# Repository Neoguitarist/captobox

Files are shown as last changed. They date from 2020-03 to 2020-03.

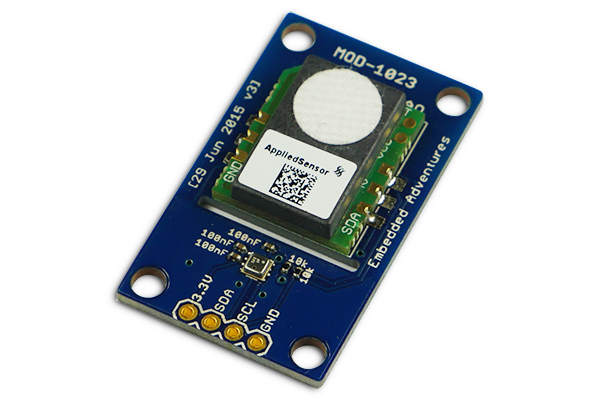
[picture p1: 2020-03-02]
resources/CAO boitier/img/cov.jpg

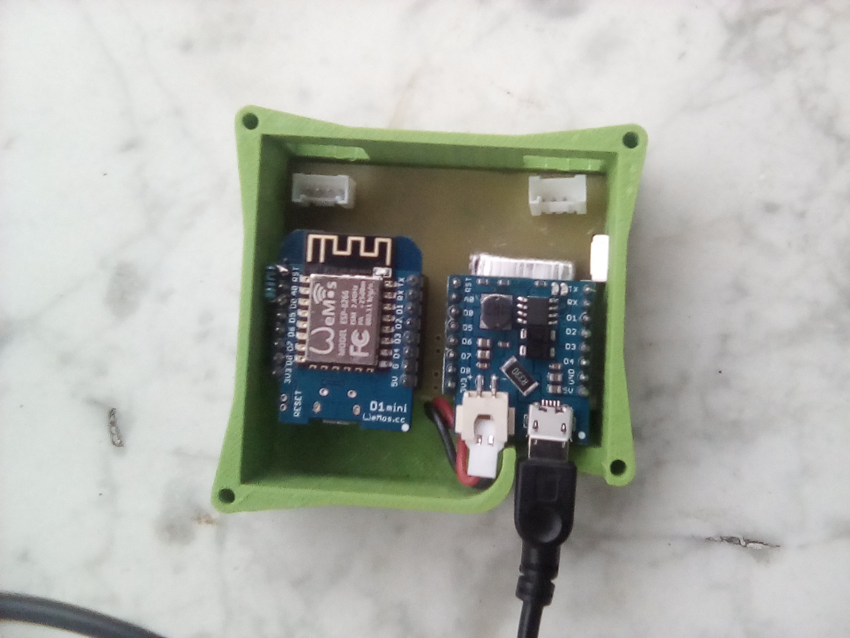
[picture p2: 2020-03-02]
resources/CAO boitier/captoboite.jpg

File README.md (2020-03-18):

**Introduction**

Ce GitHub est basé sur celui de Julien Rat : https://github.com/julienrat/captobox .

Le code a été fortement restructuré, et de nouveaux capteurs sont pris en charge.

**Capteurs pris en charge actuellement**

- M0D1023 (incluant BME280 et iAQ) :
	- MOD1023 : http://www.embeddedadventures.com/bme280_AMS-IAQ_multi_sensor_mod-1023.html
	- BME280 : https://www.bluedot.space/sensor-boards/bme280/
- BME680 : https://joy-it.net/en/products/SEN-BME680
- CCS811 : https://joy-it.net/en/products/SEN-CCS811V1

**Prise en main**

Dans le dossier "resources/prise en main", vous trouverez deux documents essentiels :
- "Description matos.pdf" : liste avec photos de l'ensemble du matériel constituant une Captobox.
- "Branchements captobox.pdf" : guide pour le branchement des différents capteurs sur le module cerveau.

**Note importante**

À l'heure actuelle, il est nécessaire de redémarrer la carte lorsqu'on change de capteur, pour que celui-ci soit détecté.

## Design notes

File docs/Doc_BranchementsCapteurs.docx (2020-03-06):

Résultat de recherche d'images pour "wemos d1 mini pull up"

Mod 1023=

- BME280 : temperature, humidity and absolute air pressure sensor

- IAQ : VOCs and C02 measurements

I2C requires the use of pull-up resistors. The board comes with the pull-up resistors enabled. If you are connecting to an existing I2C buss that already has pull-up resistors, or you are using internal pull-ups in your microcontroller, you can disable the pull-up resistors by unsoldering the 10k resistors from theMOD-1023board and making sure the pads are not connected with any residual solder. Having extra pull-ups won’t hurt anything, other than a very marginal increase in power consumption.

The AMS-IAQ takes 5 minutes to settle until first reading is available, duringwhich time it will show an ERROR reading from thestatus register

TEST:

MARCHE PAS :

MOD1023 Humidity 100pourcent sur capteur 1 et capt2 avec temperature en 2eme ?

MARCHE :

Temperature et Pression marche capt1/2 2/1

Pression et pression marche

Temp et temp marche

Temperature et CO2 marche cap1/2 et 2/1

VOC et CO2 capt1/2 2/1

….ect

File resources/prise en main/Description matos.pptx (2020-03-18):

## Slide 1

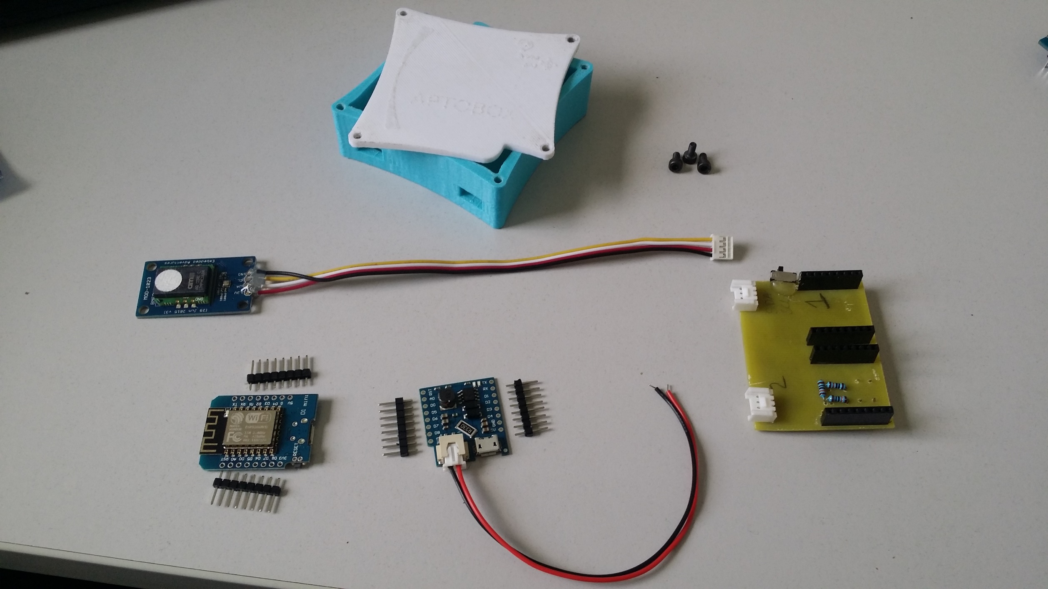
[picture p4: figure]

Boitier et couvercle
Imprimés en 3D

4 vis hexa M3 L5

capteur

Carte électronique

Nappe 4 fils
connecteur femelle

Module
Wi-Fi

broches

Module
Batterie

broches

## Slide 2

Carte électronique

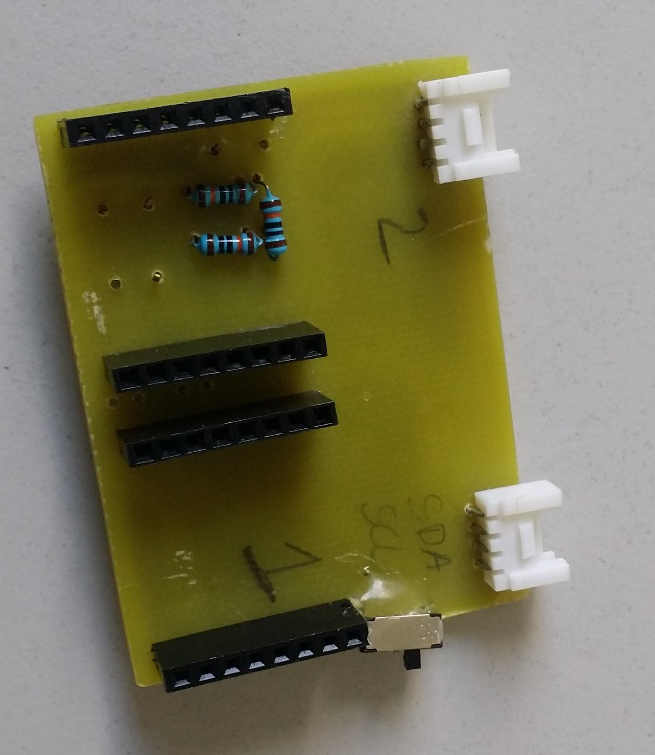
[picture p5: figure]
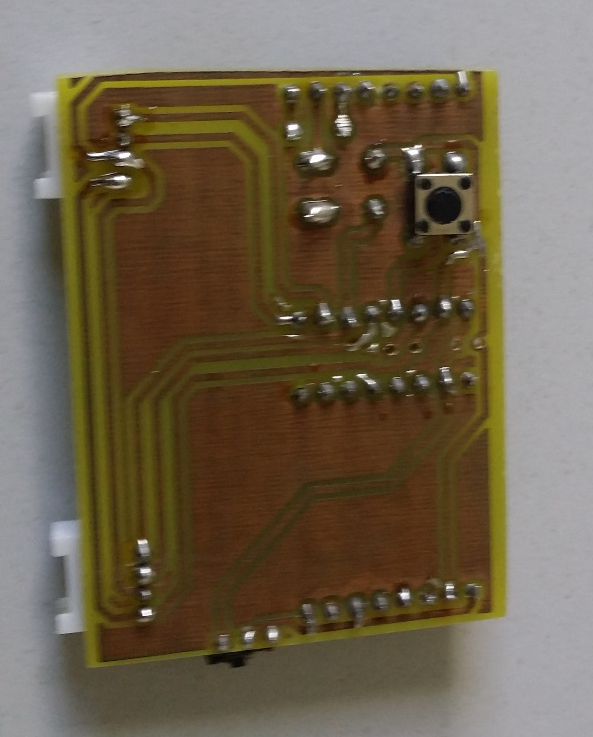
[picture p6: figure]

Bouton poussoir

Connecteurs mâle

Socket H13

Selecteur on/off

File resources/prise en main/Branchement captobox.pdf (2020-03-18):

Les petits débrouillards : Branchement Captobox

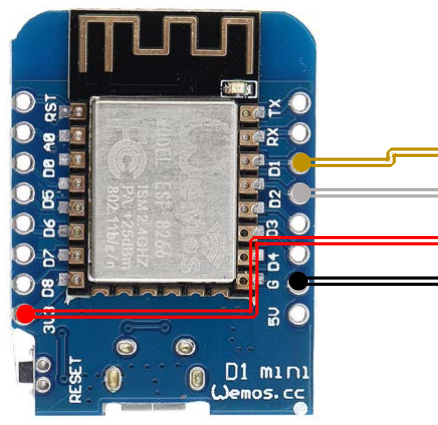
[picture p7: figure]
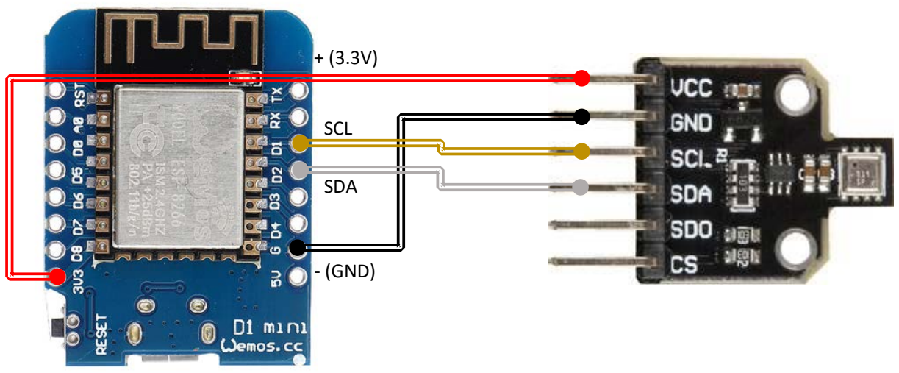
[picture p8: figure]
SDA; SCL; - (GND)

Création : 12/03/2020 par Pauline LAFOUX

Comment brancher la captobox ?
1) Le module Wemos D1 mini
C’est le « cerveau », celui qui exécute le programme. Il lis les données capteurs et les renvoie sur le wifi captobox.
Pour communiquer avec 1 ou plusieurs capteurs, il faut 4 fils :
- 2 pour l’alimentation du capteur :(+ 3.3V et – GND )
- 2 pour la communication avec le capteur (SCL et SDA)

Nous allons voir que l’on peut brancher 1 ou plusieurs capteurs en même temps
2) Les capteurs
Le BME680
Mesure : température (°C), pression (Pa), Humidité (%) et Gas (Ohm)

SDA

SCL

+ (3.3V)
- (GND)

Le CCS811
Mesure : CO2 (ppm), TVOC (ppb), température (°C)

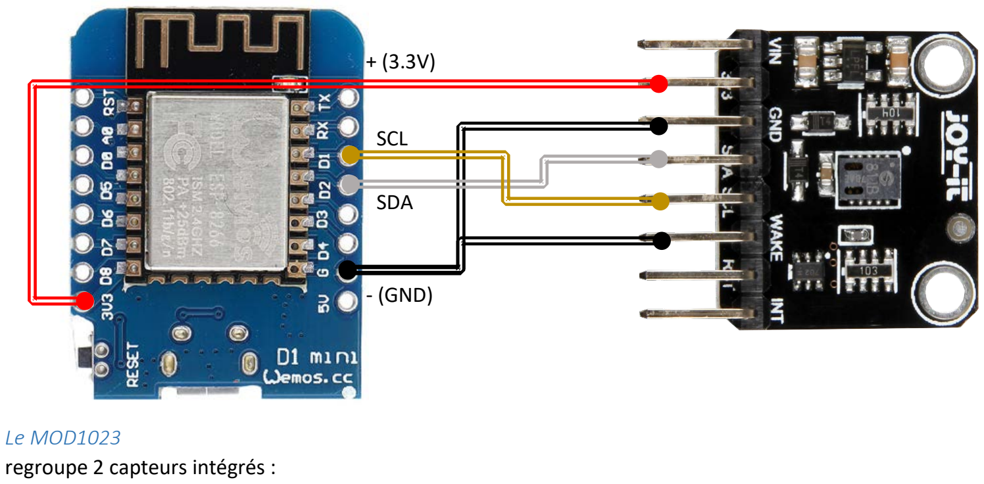
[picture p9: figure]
Le MOD1023 regroupe 2 capteurs intégrés :; SDA; SCL; - (GND)

Le BME2080 qui mesure : température (°C), humidité (%), pression (Pa)
L’IAQ qui mesure : CO2 et VOC
/!\ l’iaq a besoin de 5min pour s’initaliser avant d’afficher des valeurs valides

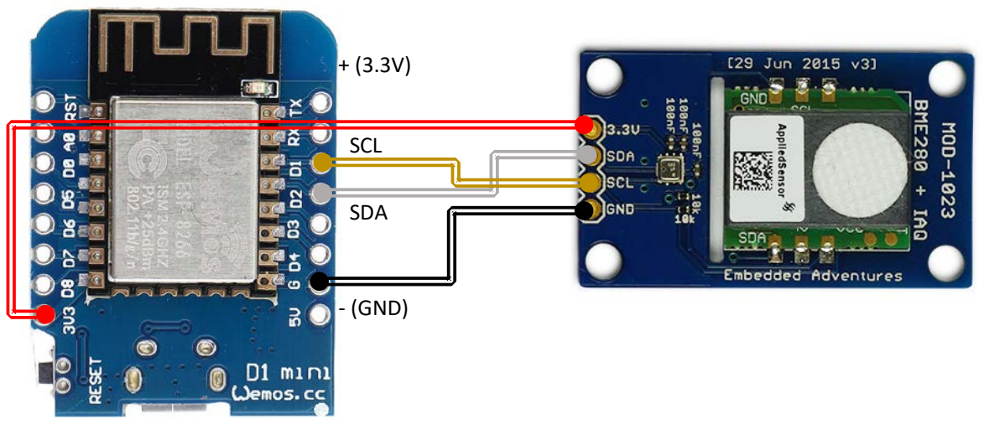
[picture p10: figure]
SDA; SCL; - (GND)

3) Branchement plusieurs capteurs
Il est possible de brancher plusieurs capteurs et de faire la lecture des données de chacun en même temps. Il suffit de faire les mêmes branchements que précédemment (en parallèle) avec tous les capteurs avec lesquels on souhaite communiquer.

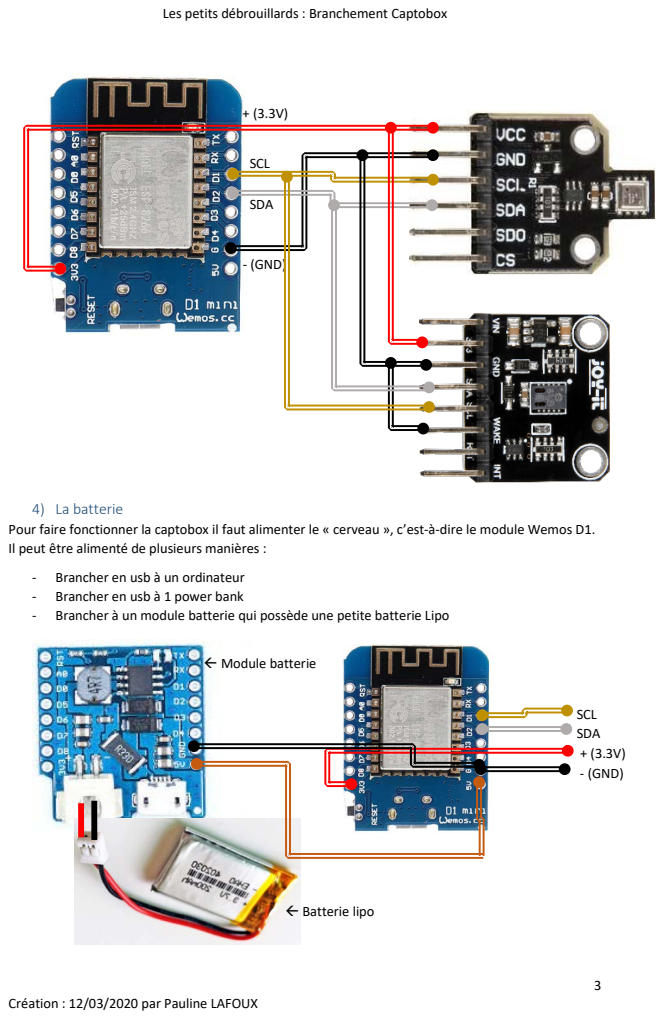
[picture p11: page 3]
SDA; SCL; - (GND); + (3.3V) - (GND); Module batterie; Batterie lipo

4) La batterie
Pour faire fonctionner la captobox il faut alimenter le « cerveau », c’est-à-dire le module Wemos D1.
Il peut être alimenté de plusieurs manières :
- Brancher en usb à un ordinateur
- Brancher en usb à 1 power bank
- Brancher à un module batterie qui possède une petite batterie Lipo

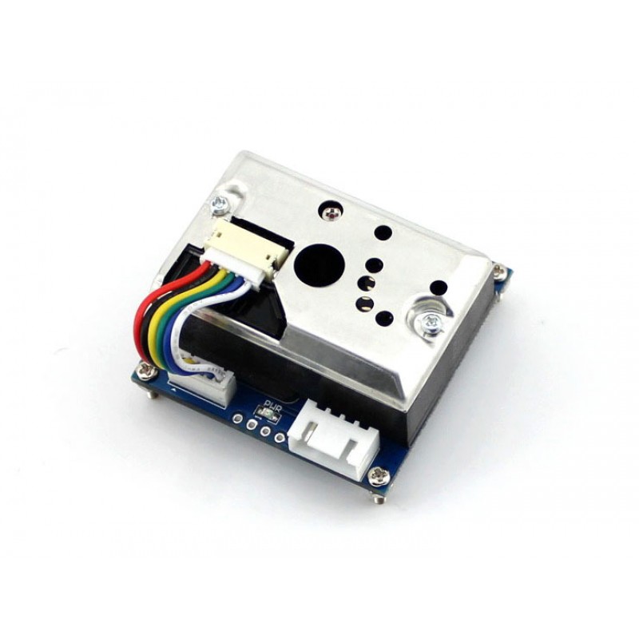
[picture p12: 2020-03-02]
resources/CAO boitier/img/dust.jpg

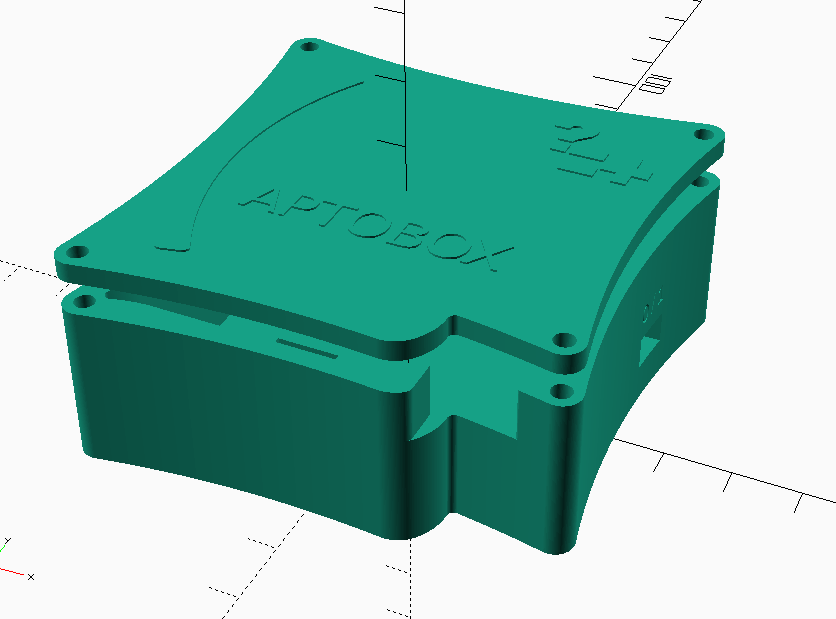
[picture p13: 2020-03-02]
resources/CAO boitier/V2/Captobox-V2.png

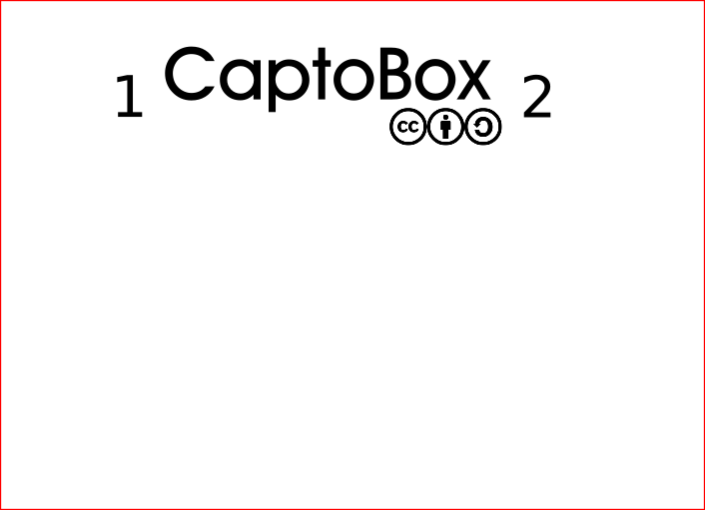
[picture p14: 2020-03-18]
resources/CAO carte électronique/fichiers sources/silk/rect133.png

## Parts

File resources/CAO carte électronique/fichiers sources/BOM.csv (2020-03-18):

Designator | Manufacturer Part Number | Quantity
SW1 | 311030008 | 1
J1,J2 | 320110034 | 2

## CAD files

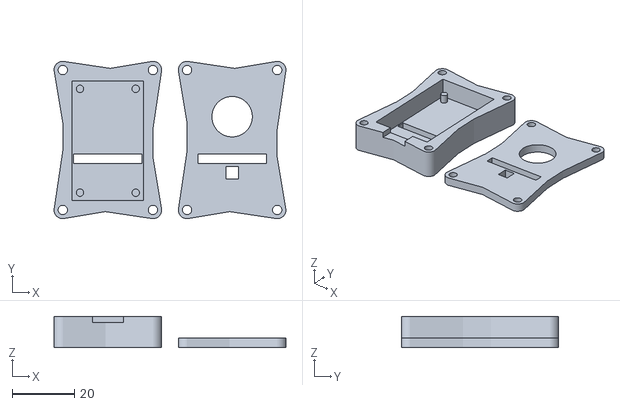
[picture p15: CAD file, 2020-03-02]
resources/CAO boitier/mod-1023.stl
74.7 x 50.7 x 10.0

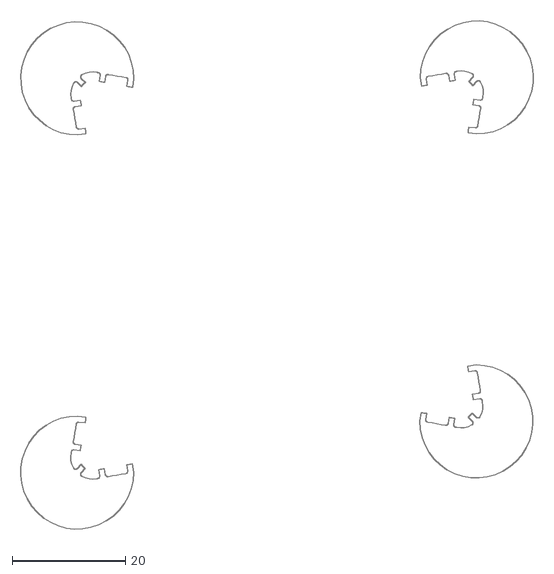
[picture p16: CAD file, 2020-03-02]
resources/CAO boitier/V2/captobox.dxf
92.3 x 91.5

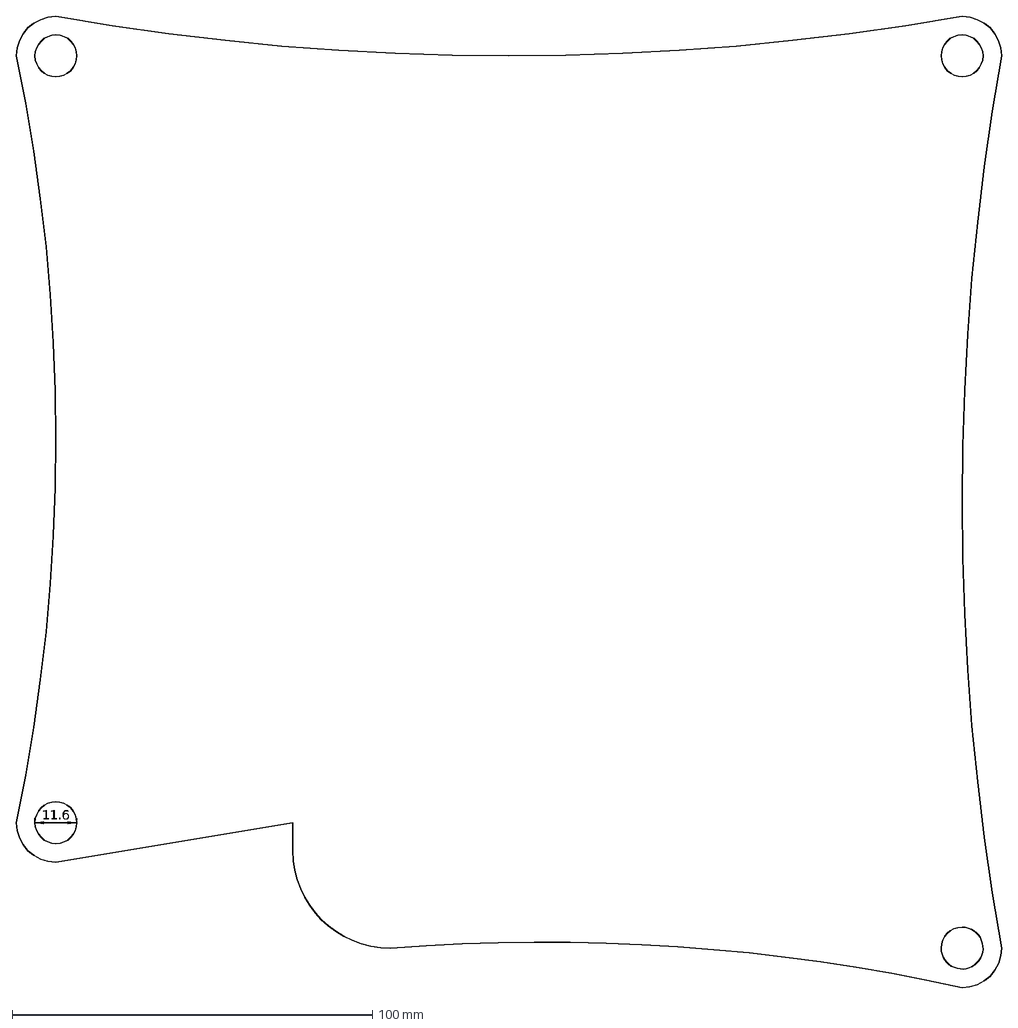
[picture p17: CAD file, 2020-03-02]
resources/CAO boitier/#capto.dxf
11.6

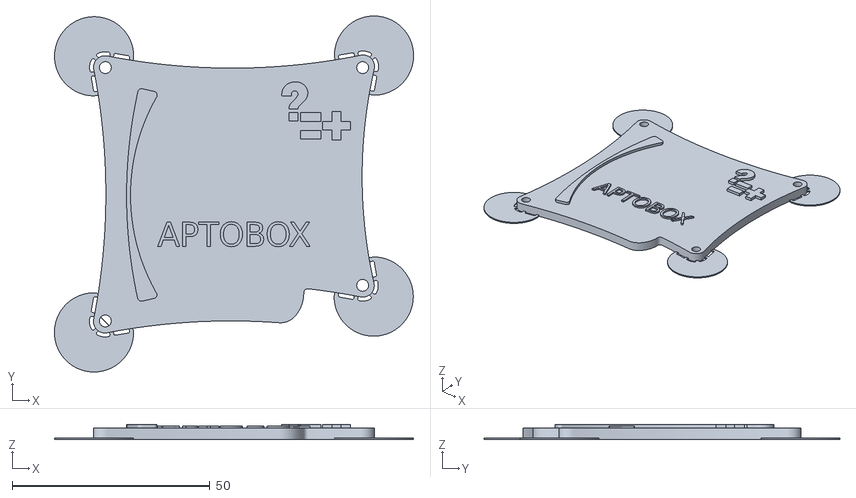
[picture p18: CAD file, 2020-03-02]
resources/CAO boitier/V2/capot-logo-support.stl
90.7 x 89.9 x 3.90

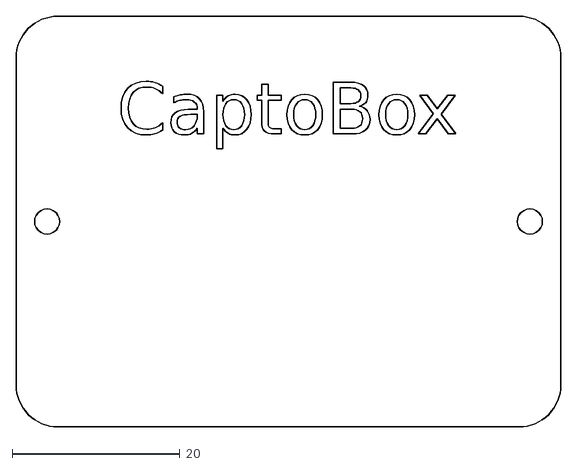
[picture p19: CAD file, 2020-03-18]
resources/CAO carte électronique/fichiers sources/silk.dxf
65.0 x 49.0

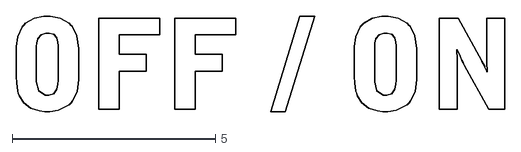
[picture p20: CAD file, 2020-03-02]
resources/CAO boitier/onoff.dxf
12.0 x 2.35

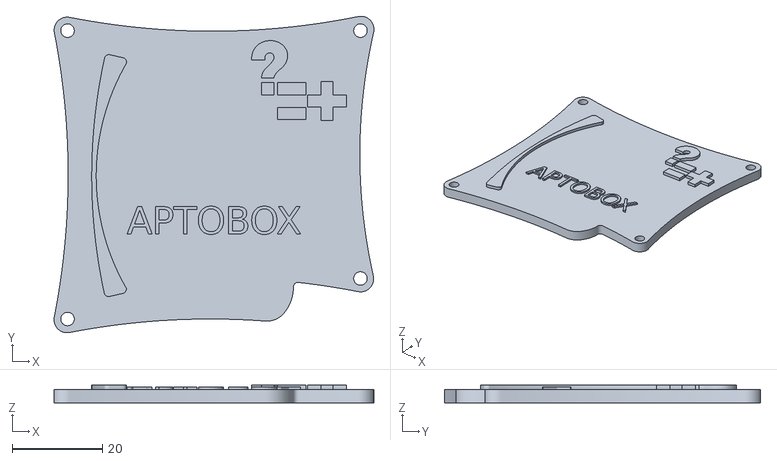
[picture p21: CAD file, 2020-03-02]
resources/CAO boitier/V2/capot-logoplusgrand-sans-support-.stl
71.0 x 70.2 x 3.90

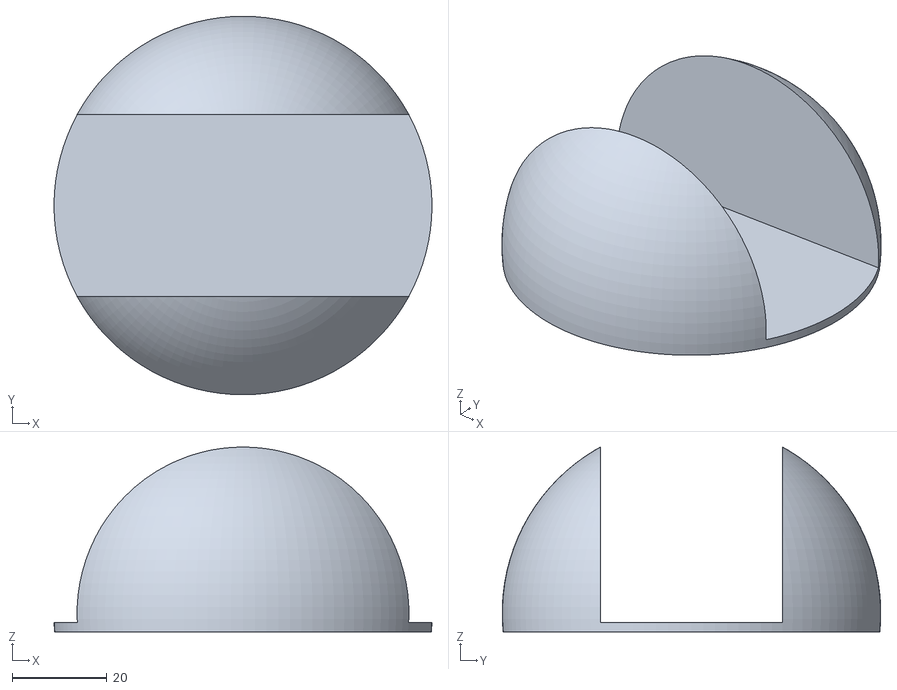
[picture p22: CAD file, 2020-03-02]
resources/CAO boitier/pied_box.stl
79.9 x 80.0 x 39.0

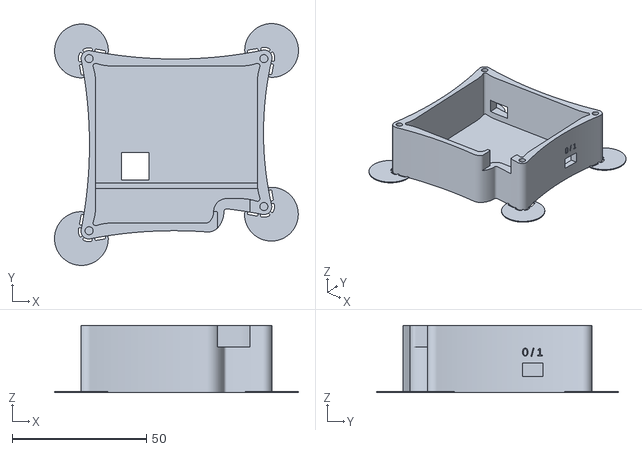
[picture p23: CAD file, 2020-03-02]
resources/CAO boitier/V2/boitier-support.stl
90.7 x 89.9 x 25.0

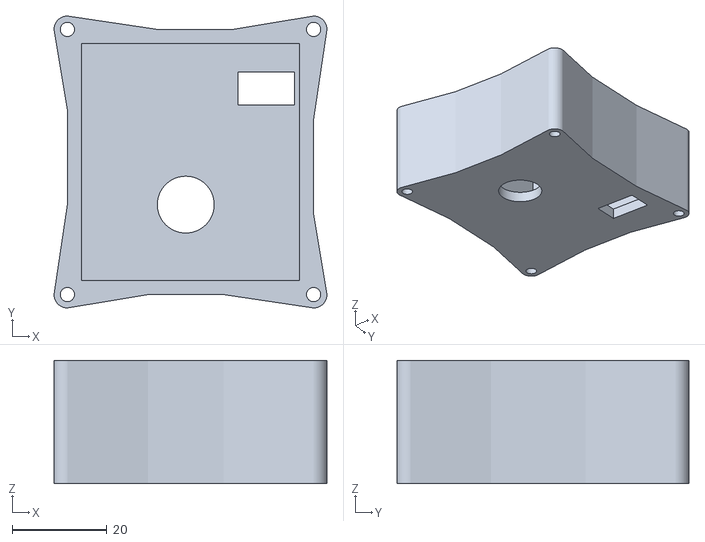
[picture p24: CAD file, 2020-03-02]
resources/CAO boitier/dust_sensor.stl
57.7 x 61.7 x 26.0

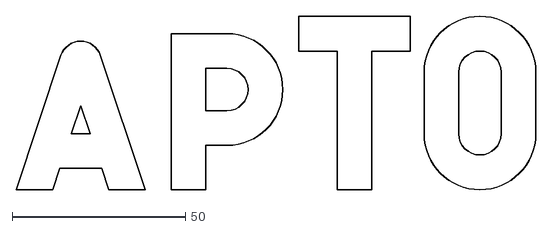
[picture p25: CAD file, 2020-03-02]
resources/CAO boitier/V2/logo_captobox.dxf
149.9 x 50.0

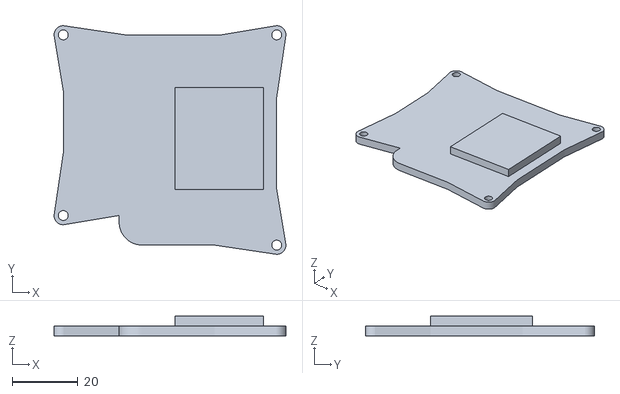
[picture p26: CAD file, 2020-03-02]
resources/CAO boitier/box_capot.stl
70.7 x 69.7 x 6.00

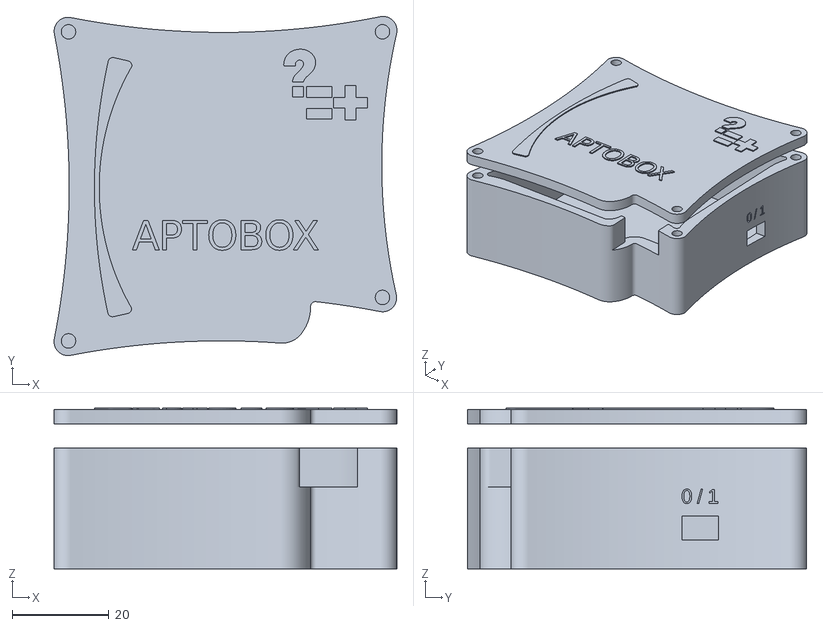
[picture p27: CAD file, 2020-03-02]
resources/CAO boitier/V2/rendu.stl
71.0 x 70.2 x 33.3

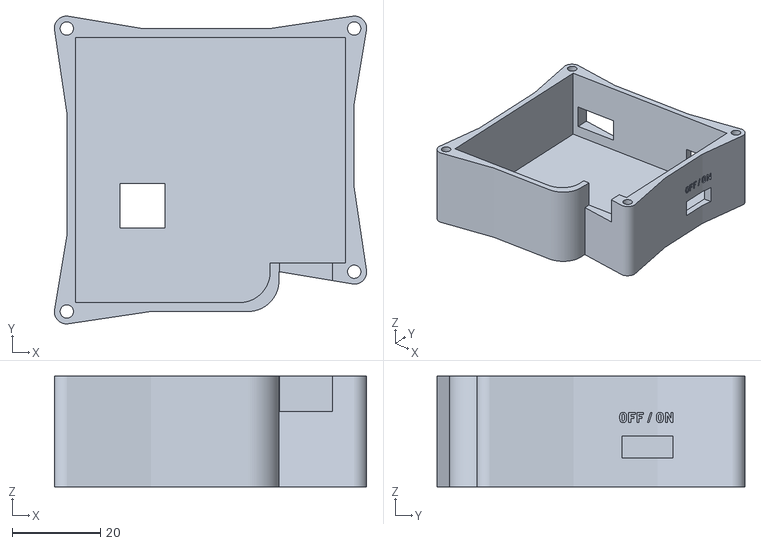
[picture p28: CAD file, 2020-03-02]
resources/CAO boitier/box.stl
70.7 x 69.7 x 25.0

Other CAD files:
resources/CAO carte électronique/fichiers sources/contour.dxf
resources/CAO boitier/wemos_battery.dxf
resources/CAO boitier/dust_sensor.scad
resources/CAO boitier/box.scad
resources/CAO boitier/mod-1023.scad
resources/CAO boitier/pied_box.scad
resources/CAO boitier/#MOD-1023.dxf
resources/CAO boitier/#dust_sensor.dxf
resources/CAO boitier/MOD-1023.dxf
resources/CAO boitier/V2/box_v2.scad
resources/CAO boitier/V2/box_v2_1.scad
resources/CAO boitier/capto.dxf
resources/CAO boitier/dust_sensor.dxf

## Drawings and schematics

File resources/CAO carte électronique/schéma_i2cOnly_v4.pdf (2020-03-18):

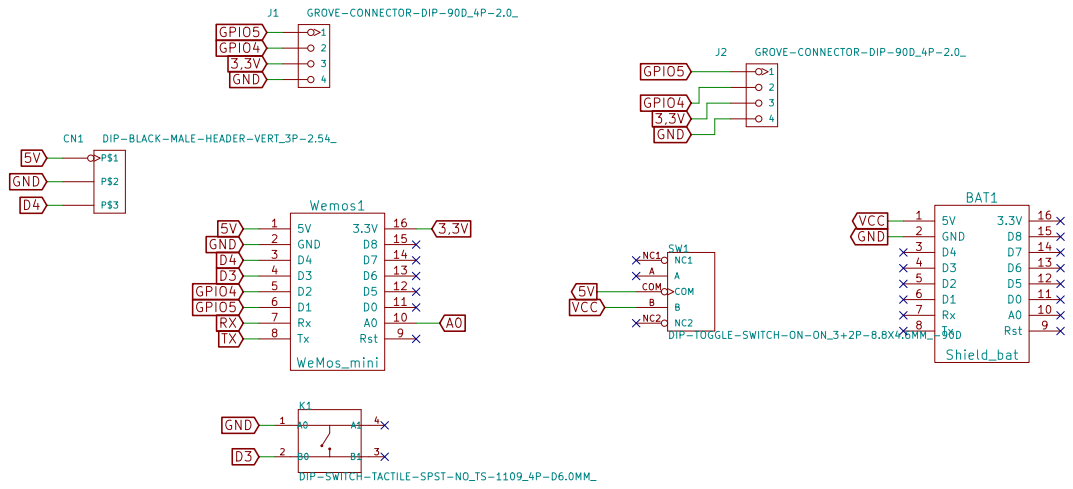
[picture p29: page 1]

File: captobox.sch Sheet: /
Id: 1/1 Title:

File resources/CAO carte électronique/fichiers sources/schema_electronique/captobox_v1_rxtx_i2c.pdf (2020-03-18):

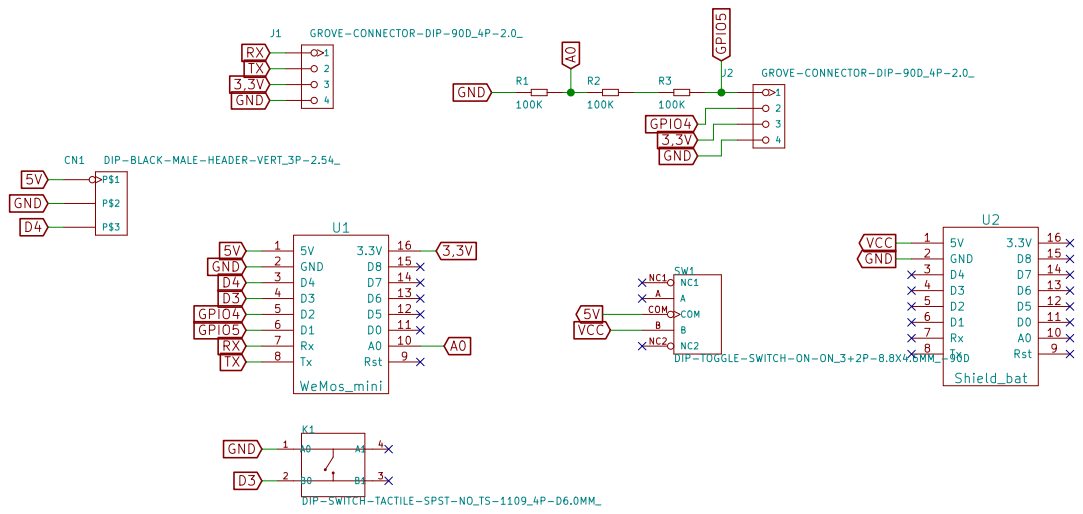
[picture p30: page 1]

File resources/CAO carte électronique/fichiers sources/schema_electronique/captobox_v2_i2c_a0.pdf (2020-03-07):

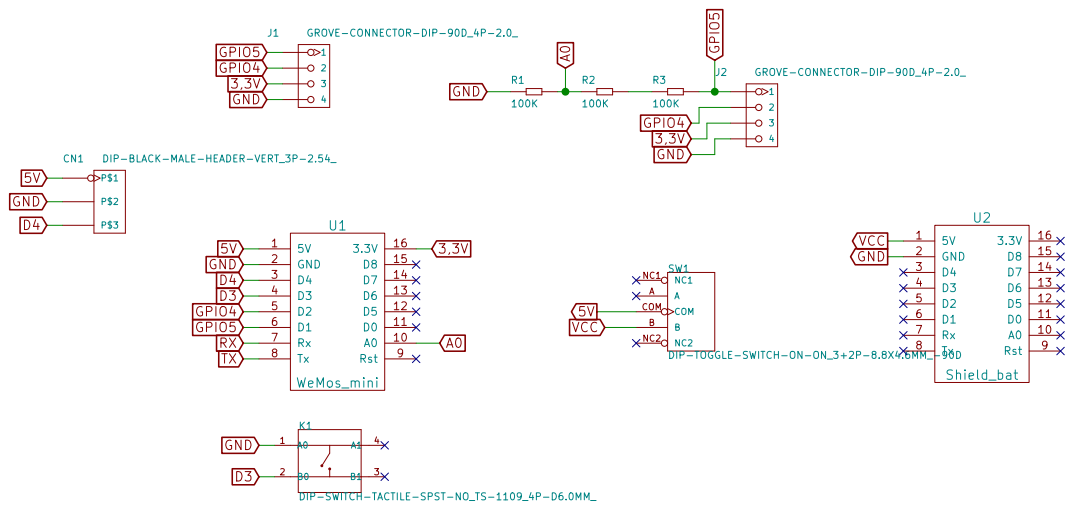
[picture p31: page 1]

File: captobox.sch Sheet: /
Id: 1/1 Title:

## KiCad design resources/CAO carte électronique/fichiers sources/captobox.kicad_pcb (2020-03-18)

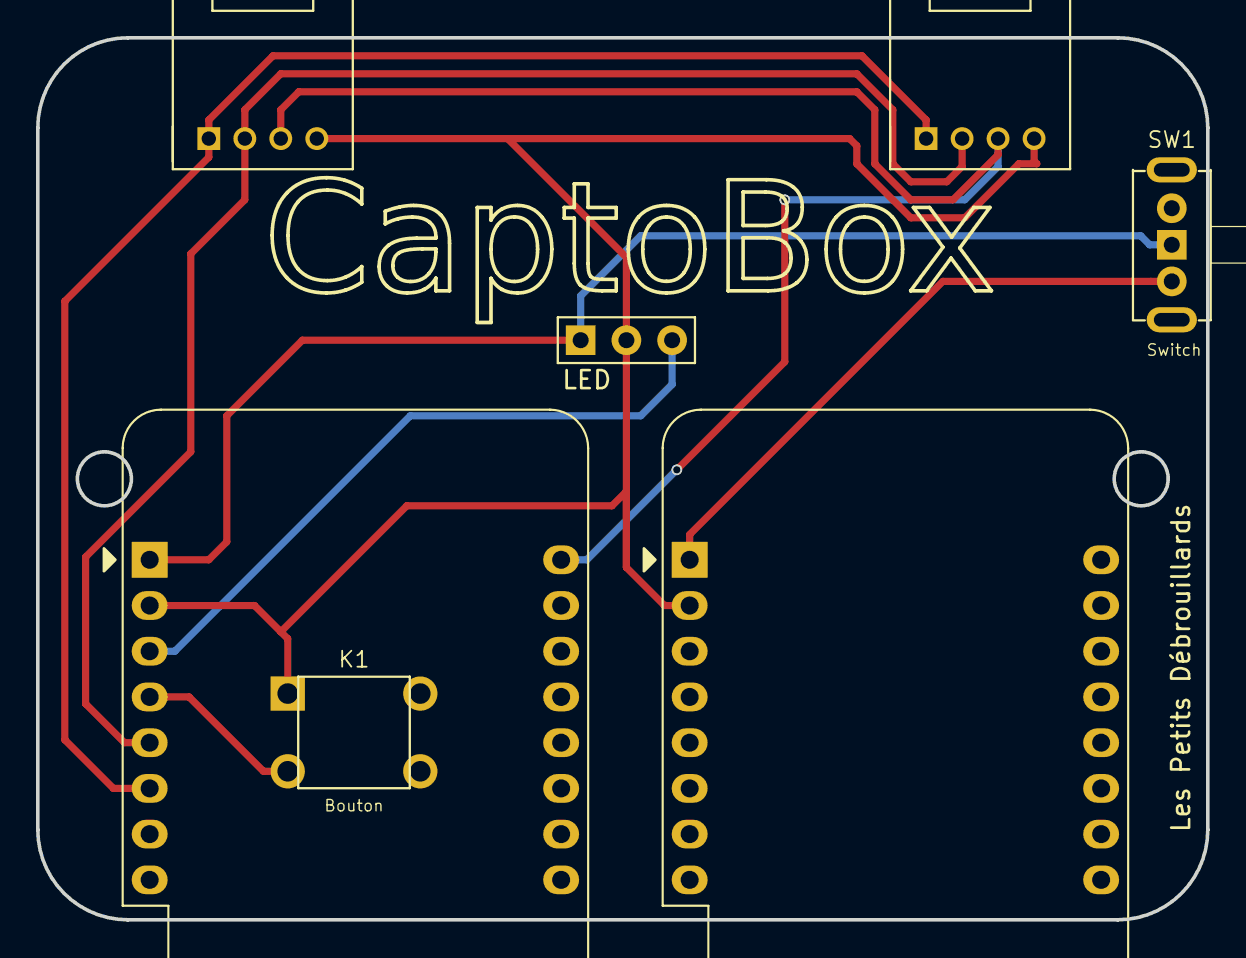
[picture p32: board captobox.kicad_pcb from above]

Board: 2 copper layers, 65.0 x 49.0 mm, 7 parts (0 on the bottom side), 8 nets.

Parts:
BAT1: Shield_bat; WEMOS_D1_mini_light2
J1, J2: GROVE-CONNECTOR-DIP-90D_4P-2.0_; HW4-2.0-90D
K1: Bouton; SW4-6.0X6.0X5.0MM
LED: DIP-BLACK-MALE-HEADER-VERT_3P-2.54_; H3-2.54
SW1: Switch; SW5-2.0-8.8X4.4X4.7MM-90D
Wemos1: WeMos_mini; WEMOS_D1_mini_light2

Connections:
3,3V: J1.3, J2.3, Wemos1.16
5V: LED.1, SW1.COM, Wemos1.1
D3: K1.2, Wemos1.4
D4: LED.3, Wemos1.3
GND: BAT1.2, J1.4, J2.4, K1.1, LED.2, Wemos1.2
GPIO4: J1.2, J2.2, Wemos1.5
GPIO5: J1.1, J2.1, Wemos1.6
VCC: BAT1.1, SW1.B

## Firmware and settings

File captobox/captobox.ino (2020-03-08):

#include <unordered_map>
//Import des bibliothèques ESP8266
#include <ESP8266WiFi.h>
#include <WiFiClient.h>
#include <ESP8266WebServer.h>
#include <ESP8266mDNS.h>
#include <ESP8266httpUpdate.h>
#include <TimeLib.h>
#include <elapsedMillis.h>
#include "OneButton.h"
#include <Adafruit_NeoPixel.h>
//Import des bibliotheques SPIFFS
#include "FS.h"
#include "src/spiffs_lib.h"
#include "src/Config.h"
#include "src/MOD1023Sensor.h"
#include "src/BME680Sensor.h"
#include "src/CCS811Sensor.h"
#include "src/Measure.h"

const String version = "version beta++";

Config config;
MOD1023Sensor mod1023(Serial);
BME680Sensor bme680(Serial);
CCS811Sensor ccs811(Serial);

std::unordered_map<std::string, MeasureReader> measureReaders =
	{
		{ "mod1023_co2", MeasureReader("MOD1023 - CO2 (ppm)", Measure::CO2, 450, 2000, []() { return mod1023.read_co2(); }) },
		{ "mod1023_hum", MeasureReader("MOD1023 - Humidité (%)", Measure::HUMIDITY, 0, 100, []() { return mod1023.read_humidity(); }) },
		{ "mod1023_pres", MeasureReader("MOD1023 - Pression (hPa)", Measure::PRESSURE, 300, 1100, []() { return mod1023.read_pressure(); }) },
		{ "mod1023_temp", MeasureReader("MOD1023 - Température (°C)", Measure::TEMPERATURE, -40, 85, []() { return mod1023.read_temperature(); }) },
		{ "mod1023_tvoc", MeasureReader("MOD1023 - TVOC (ppb)", Measure::TVOC, 125, 600, []() { return mod1023.read_tvoc(); }) },
		{ "bme680_hum", MeasureReader("BME680 - Humidité (%)", Measure::HUMIDITY, 0, 100, []() { return bme680.read_humidity(); }) },
		{ "bme680_temp", MeasureReader("BME680 - Température (°C)", Measure::TEMPERATURE, -40, 85, []() { return bme680.read_temperature(); }) },
		{ "ccs811_co2", MeasureReader("CCS811 - CO2 (ppm)", Measure::CO2, 450, 2000, []() { return ccs811.read_co2(); }) },
		{ "ccs811_temp", MeasureReader("CCS811 - Température (°C)", Measure::TEMPERATURE, -40, 85, []() { return ccs811.read_temperature(); }) },
		{ "ccs811_tvoc", MeasureReader("CCS811 - TVOC (ppb)", Measure::TVOC, 125, 600, []() { return ccs811.read_tvoc(); }) },
	};

String save = "false";
boolean writeTitle = true;
OneButton button(D3, true);
Adafruit_NeoPixel pixels = Adafruit_NeoPixel(1, D4, NEO_GRB + NEO_KHZ800);

void setup()
{
	delay(1000);

	Serial.begin(9600); //debug série

	pixels.begin();
	pixels.setPixelColor(0, pixels.Color(10, 0, 0));
	pixels.show();

	button.attachDuringLongPress(erase_save);
	button.attachDoubleClick(toggle_save);

	// reset pin connected to rst
	pinMode(D0, OUTPUT);

	digitalWrite(D0, LOW);

	pinMode(BUILTIN_LED, OUTPUT);
	digitalWrite(BUILTIN_LED, HIGH);

	// démarrage de la gestion SPIFFS
	SPIFFS.begin(); 

	if (!read_config("/config.txt"))
	{
		Serial.println("Program stopped.");
		return;
	}

	if (config.client_mode.equals("true"))
	{
		WiFi.mode(WIFI_STA);
		connect_wifi(config.ssid_client.c_str(), config.password_client.c_str());
		web_update();
	}
	else
	{
		WiFi.mode(WIFI_AP);
		WiFi.softAP("captobox", "", 2);
	}

	MDNS.begin("captobox");
	MDNS.addService("http", "tcp", 80);

	// demarrage dur serveur de fichiers
	setup_server();
	server.begin();

	Serial.println("\nConfiguration");
	Serial.println("================================================");
	config.print(Serial);
	Serial.println("================================================");

	Serial.println("Initialisation des capteurs... ");
	mod1023.init();
	bme680.init();
	ccs811.init();
	Serial.println("OK.\n");

	digitalWrite(BUILTIN_LED, HIGH);

	pixels.setPixelColor(0, pixels.Color(0, 10, 0));
	pixels.show();
}

void loop()
{
	elapsedMillis timeElapsed;

	server.handleClient();
	button.tick();

	if (timeElapsed > config.frequency.toInt())
	{
		if (config.stream.equals("true"))
		{
			Serial.println("tick : " + millis());

			send_json(config.host.c_str(), config.request,
				String(measureReaders[config.capt1].read()),
				String(measureReaders[config.capt2].read()));

			Serial.println("tick : " + millis());
		}

		savedata();

		timeElapsed = 0;
	}
}

void setup_server()
{
	server.on("/", HTTP_GET, []()
		{
			if (!handleFileRead("/index.html")) server.send(404, "text/plain", "FileNotFound");
		});
	server.on("/config.html", HTTP_GET, []()
		{
			if (!handleFileRead("/config.html")) server.send(404, "text/plain", "FileNotFound");
		});

	server.on("/write", HTTP_GET, []()
		{
			File configFile;

			config.capt1 = server.arg("capt1").c_str();
			config.capt2 = server.arg("capt2").c_str();
			config.frequency = server.arg("frequency");
			config.client_mode = server.arg("client");
			config.ssid_client = server.arg("ssid");
			config.password_client = server.arg("password");
			config.request = server.arg("request");
			//config.host = server.arg("config.host");
			config.stream = server.arg("stream");

			config.print(Serial);

			server.send(200, "text/plain", "okay");

			configFile = SPIFFS.open("/config.txt", "w");

			server.send(200, "text/plain", "ecriture spiffs");

			config.save(configFile);
			configFile.close();

			Serial.println("fichier enregistré");

			delay(500);
			digitalWrite(D0, LOW);
			//ESP.restart();
			delay(500);
			//reset de l'esp (D0 donnecté avec une resistance de 510 ohms à RST)
		});

	server.on("/capt1_raw", HTTP_GET, []()
		{
			server.send(200, "text/json", String(measureReaders[config.capt1].read()));
		});

	server.on("/capt2_raw", HTTP_GET, []()
		{
			server.send(200, "text/json", String(measureReaders[config.capt2].read()));
		});

	server.on("/lecture", HTTP_GET, []()
		{
			MeasureReader& capt1 = measureReaders[config.capt1];
			MeasureReader& capt2 = measureReaders[config.capt2];
			String json = "{";
			json += "\"capt1\":\"" + String(capt1.read()) + "\"";
			json += ", \"name_capt1\":\"" + capt1.name + "\"";
			json += ", \"min_capt1\":\"" + String(capt1.min) + "\"";
			json += ", \"max_capt1\":\"" + String(capt1.max) + "\"";
			json += ", \"capt2\":\"" + String(capt2.read()) + "\"";
			json += ", \"name_capt2\":\"" + capt2.name + "\"";
			json += ", \"min_capt2\":\"" + String(capt2.min) + "\"";
			json += ", \"max_capt2\":\"" + String(capt2.max) + "\"";
			json += ", \"save\":\"" + save + "\"";
			json += "}";

			server.send(200, "text/json", json);

			json = String();
		});

	server.on("/lecture_config", HTTP_GET, []()
		{
			String json = "{";
			json += "\"ssid_client\":\"" + config.ssid_client + "\"";
			json += ", \"password_client\":\"" + config.password_client + "\"";
			json += ", \"request\":\"" + config.request + "\"";
			json += ", \"client\":\"" + config.client_mode + "\"";
			json += ", \"frequency\":\"" + config.frequency + "\"";
			json += ", \"capt1\":\"" + String(config.capt1.c_str()) + "\"";
			json += ", \"capt2\":\"" + String(config.capt2.c_str()) + "\"";
			json += ", \"host\":\"" + config.host + "\"";
			json += ", \"stream\":\"" + config.stream + "\"";
			json += ", \"save\":\"" + save + "\"";
			json += ", \"vers\":\"" + version + "\"";
			json += "}";

			server.send(200, "text/json", json);

			json = String();
		});

	//  == upload firmware

	server.onFileUpload([]()
		{
			HTTPUpload& upload = server.upload();
			
			if (server.uri() != "/update")
			{
				return;
			}

			if (upload.status == UPLOAD_FILE_START)
			{
				uint32_t maxSketchSpace = (ESP.getFreeSketchSpace() - 0x1000) & 0xFFFFF000;
				
				Serial.println("Upload Name: " + upload.filename);

				if (upload.filename.endsWith(".spiffs.bin"))
				{
					Serial.println("update to spiffs");

					// start with max available size
					if (!Update.begin(maxSketchSpace, U_SPIFFS))
					{
						Update.printError(Serial);
						Serial.println("ERROR");
					}
				}
				else if (upload.filename.endsWith(".d1_mini.bin"))
				{
					Serial.println("update to flash");

					// start with max available size
					if (!Update.begin(maxSketchSpace))
					{
						Update.printError(Serial);
						Serial.println("ERROR");
					}
				}
			}
			else if (upload.status == UPLOAD_FILE_WRITE)
			{
				Update.write(upload.buf, upload.currentSize);
			}
			else if (upload.status == UPLOAD_FILE_END)
			{
				Update.end(true);
			}
		});

	server.on("/update", HTTP_POST, []()
		{
			server.sendHeader("Connection", "close");
			server.sendHeader("Access-Control-Allow-Origin", "*");
			server.send(200, "text/plain", (Update.hasError()) ? "FAIL" : "OK rebootez la captobox");
			delay(50);
			digitalWrite(D0, LOW); //reset de l'esp (D0 donnecté avec une resistance de 510 ohms à RST)
		});

	server.on("/save_spiff", HTTP_GET, []()
		{
			server.send(200, "text/plain", "save ok");
			Serial.println("commande sauvegarde OK");
			save = "true";
		});

	server.on("/stop_save_spiff", HTTP_GET, []()
		{
			server.send(200, "text/plain", "save stop");
			save = "false";
		});

	server.on("/erase_save_spiff", HTTP_GET, []()
		{

		});

	server.onNotFound([]()
		{
			if (!handleFileRead(server.uri()))
				server.send(404, "text/plain", "FileNotFound");
		});
}

void savedata()
{
	if (!save.equals("true"))
	{
		pixels.setPixelColor(0, pixels.Color(0, 10, 0));
		pixels.show();
		return;
	}

	File saveFile = SPIFFS.open("/save.csv", "a");
	MeasureReader& capt1 = measureReaders[config.capt1];
	MeasureReader& capt2 = measureReaders[config.capt2];
	String dateStr;

	pixels.setPixelColor(0, pixels.Color(0, 0, 10));
	pixels.show();

	if (writeTitle)
	{
		saveFile.println("date:" + capt1.name + ":" + capt2.name);
		writeTitle = false;
	}

	dateStr = String(year());

	for (const int &token :
		std::vector<int>{ month(), day(), hour(), minute(), second() })
	{
		dateStr += "," + String(token);
	}

	saveFile.println(dateStr + ":" + String(capt1.read()) + ":" + String(capt2.read()));
	saveFile.close();
}

void erase_save()
{
	SPIFFS.remove("/save.csv");

	writeTitle = true;

	pixels.setPixelColor(0, pixels.Color(10, 0, 0));
	pixels.show();
	delay(50);

	pixels.setPixelColor(0, pixels.Color(0, 0, 10));
	pixels.show();
	delay(50);
}

void toggle_save()
{
	if (save.equals("true"))
	{
		save = "false";
	}
	else
	{
		save = "true";
	}
}

void connect_wifi(const char* ssid, const char* password)
{
	int timeout = 0;

	WiFi.begin(ssid, password);
	Serial.println("connection en cours...");

	while (WiFi.status() != WL_CONNECTED)
	{
		delay(500);
		timeout++;

		Serial.print(".");

		if (timeout > 50)
		{
			String configLine;
			File configuration = SPIFFS.open("/config.txt", "w");

			Serial.println("timeout");

			for (const String &token :
				std::vector<String>{
					String(config.capt1.c_str()), String(config.capt2.c_str()), config.frequency,
					"false", config.ssid_client, config.password_client,
					config.request, config.host, config.stream })
			{
				configLine += token + "$";
			}

			configuration.print(configLine);
			configuration.close();
			delay(500);

			digitalWrite(D0, LOW);
			ESP.reset();
			delay(500);
		}
	}

	Serial.println("\nWiFi connected\nIP address:\n" + String(WiFi.localIP()));
}

bool read_config(const char* fichier)
{
	File  file = SPIFFS.open(fichier, "r");

	if (!file)
	{
		Serial.println("Failed to open the configuration file (path: \"" + String(fichier) + "\").");
		return false;
	}
	
	config.load(file);

	return true;
}

void send_json(const char* host_in, String url_in, String data1, String data2)
{
	WiFiClient client;
	String contentType = "application/json";
	String json = "{";
	json += "\"value1\":\"" + data1 + "\"";
	json += ", \"value2\":\"" + data2 + "\"";
	json += "}";

	const int httpPort = 80;

	if (!client.connect(host_in, httpPort))
	{
		Serial.print("Requesting URL error: ");
		//stream = "false";
		return;
	}

	Serial.println("Requesting URL: " + url_in);

	// This will send the request to the server
	client.print(String("GET ") + url_in + " HTTP/1.1\r\n" +
		"Host: " + host_in + "\r\n" +
		"Cache-Control: no-cache" + "\r\n" +
		"Content-Type: " + contentType + "\r\n" +
		"Content-Length: " + json.length() + "\r\n" +
		"\r\n" +
		json + "\r\n" +
		"Connection: close\r\n\r\n");
}

void read_sensors()
{
	Serial.println("lecture des capteurs");
	Serial.println("capteur 1 : " + String(measureReaders[config.capt1].read()));
	Serial.println("capteur 2 : " + String(measureReaders[config.capt2].read()));
	delay(100);
}

void web_update()
{
	t_httpUpdate_return ret = ESPhttpUpdate.update("192.30.253.112", 80, "/julienrat/captobox/raw/master/bin/captobox.bin", "optional current version string here");
	
	switch (ret)
	{
		case HTTP_UPDATE_FAILED:
			Serial.println("[update] Update failed.");
			break;
		case HTTP_UPDATE_NO_UPDATES:
			Serial.println("[update] Update no Update.");
			break;
		case HTTP_UPDATE_OK:
			Serial.println("[update] Update ok."); // may not called we reboot the ESP
			break;
	}
}

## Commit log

2020-03-02 Reprise des sources de https://github.com/julienrat/captobox . Restructuration du code.
2020-03-06 simple program de test pour le ccs811
2020-03-06 Poursuite de la refactorisation du code : maintenant, tout compile, et les capteurs MOD1023 et BME680 sont de nouveau utilisables ! Mise à jour du .gitignore pour ne plus conserver les produits de co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
2020-03-07 Implémentation de la prise en charge du capteur CCS811. Ajout d'un dossier "docs", contenant les manuels des capteurs BME680 et CCS811, ainsi que des aides concernant la captobox.
2020-03-08 Refacto de config.html.
2020-03-08 Simplification du CSS. Suppression des fichiers inutiles dans le dossier data. Simplification et clarification du dossier data.
2020-03-13 Docs/tuto pour la construction de la captobox
2020-03-18 Ajout de commentaires dans le code. Ajout de fichiers de ressources (CAO et autres). Réorganisation des dossiers.
    [#MOD-1023.dxf, #capto.dxf, #dust_sensor.dxf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]
2020-03-18 Déplacement des documents de prise en main.
